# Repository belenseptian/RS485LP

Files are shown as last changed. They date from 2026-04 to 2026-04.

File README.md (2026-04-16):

-----

# RS-485LP (Low Power RS485 Node)

[](https://www.gnu.org/licenses/gpl-3.0)
[](https://platformio.org/)

**RS-485LP** is an open-source RS485 converter featuring a custom PCB and optimized PlatformIO firmware. It is designed to minimize power consumption for battery-operated sensors and remote monitoring systems.

🔗 **Official Project Website:** [https://belenseptian.github.io/RS485LP/](https://belenseptian.github.io/RS485LP/)

-----

### 📟 Board Design Preview
Below are the top and bottom views of the RS-485LP PCB.

| Top View (Components) | Bottom View (Traces) |
| :---: | :---: |
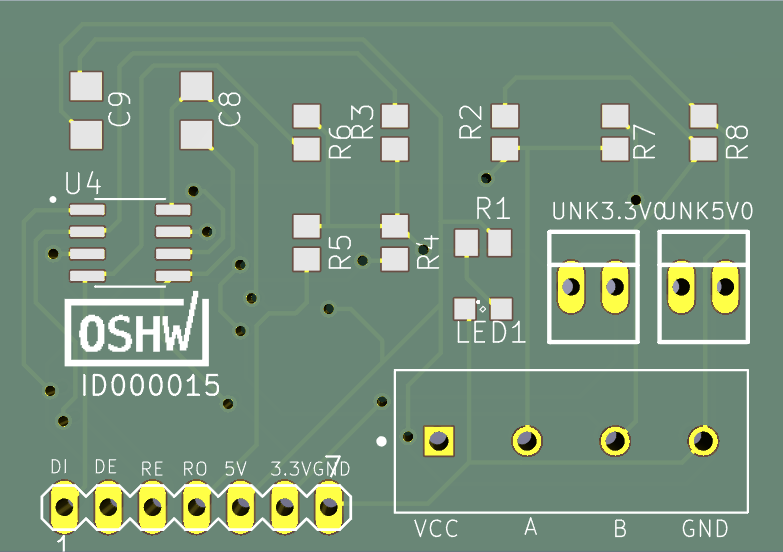
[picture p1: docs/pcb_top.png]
PCB Top
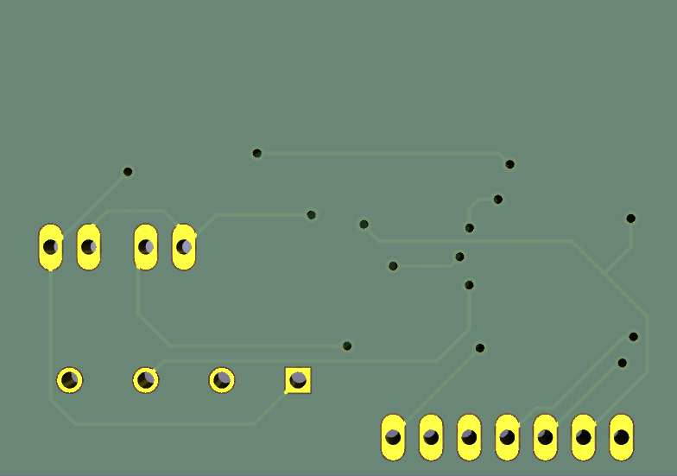
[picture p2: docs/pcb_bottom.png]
PCB Bottom
|  |  |

-----

## 🚀 Features

  * **Sleep & Shutdown Optimization:** Optimized for deep-sleep and hardware shutdown modes to achieve micro-amp current draw during periods of inactivity.
  * **RS485 Protocol:** Reliable differential signaling for long-range data transmission.
  * **PlatformIO Integrated:** Easy-to-compile and upload firmware using VS Code.
  * **Compact Form Factor:** Small PCB footprint suitable for tight enclosures.

-----

## 🛠 Hardware Fabrication

### 1\. Obtain KiCad Files

The PCB design is created using **KiCad**. You can find the project files in the `pcb/` directory.

1.  Clone this repository to get the full KiCad project.
2.  Open the project in KiCad to view the schematic or modify the layout.

### 2\. Ordering from PCBWay (or similar)

Most modern PCB manufacturers allow you to upload the KiCad file directly:

1.  **Option A (Direct):** Upload the `.kicad_pcb` file from the `pcb/` folder directly to [PCBWay's Instant Quote](https://www.pcbway.com/).
2.  **Option B (Manual Gerber Export):** - In KiCad, go to **File \> Fabrication Outputs \> Gerbers (.gbr)**.
      - Generate the drill files and zip all outputs together.
      - Upload the resulting `.zip` file to the manufacturer.

-----

## 💻 Software Setup

This project uses **PlatformIO** inside **Visual Studio Code**.

### Prerequisites

  * **VS Code:** [Download here](https://code.visualstudio.com/)
  * **PlatformIO IDE Extension:** Install this via the VS Code Extensions marketplace.

### Project Installation

1.  Clone the repository:
    ```bash
    git clone https://github.com/belenseptian/RS485LP.git
    ```
2.  Open VS Code and go to **PlatformIO Home** \> **Open Project**.
3.  Navigate to the `firmware/` folder and select it.

-----

## 📤 Uploading & Testing Sleep Mode

1.  **Connect Hardware:** Connect your board to your computer using a USB-to-Serial adapter.
2.  **Build & Upload:** Use the **Checkmark (✅)** to compile and the **Arrow (➡️)** to flash.
3.  **Verify Shutdown:**
      - Open the **Serial Monitor (🔌)** (Baud rate: `115200`).
      - The monitor should display "Entering Sleep Mode..." or "Shutting Down...".
      - Use a Multimeter or Power Profiler to measure the current draw; it should drop significantly as the MCU enters the deep sleep/shutdown state.
4.  **Wake-up Trigger:** Ensure you have configured the wake-up source (e.g., Timer or External Interrupt on the RS485 RX pin).

-----

## 🔌 Wiring Diagram

| Pin Name | Description | Connection |
| :--- | :--- | :--- |
| **VCC** | Power Input | Depend on the sensor specifications |
| **GND** | Ground | Ground |
| **A** | RS485 Data+ | Connect to Bus A |
| **B** | RS485 Data- | Connect to Bus B |

-----

## 📂 Project Structure

```text
RS-485LP/
├── firmware/           # PlatformIO project files
│   ├── src/            # Main application code (Sleep/Shutdown logic)
│   └── platformio.ini  # Project configuration
├── pcb/                # KiCad project files (.kicad_pcb, .kicad_sch)
├── docs/               # Datasheets and additional documentation
└── README.md           # This file
```

-----

## 📜 License

This project is licensed under the **GNU General Public License v3.0** - see the [LICENSE](https://www.google.com/search?q=LICENSE) file for details.

## 🤝 Contributing

Contributions are welcome\! If you have suggestions for better power-gating or further reducing shutdown current, feel free to open an **Issue** or submit a **Pull Request**.

-----

**Developed by [Belen Septian](https://www.google.com/search?q=https://github.com/belenseptian)**

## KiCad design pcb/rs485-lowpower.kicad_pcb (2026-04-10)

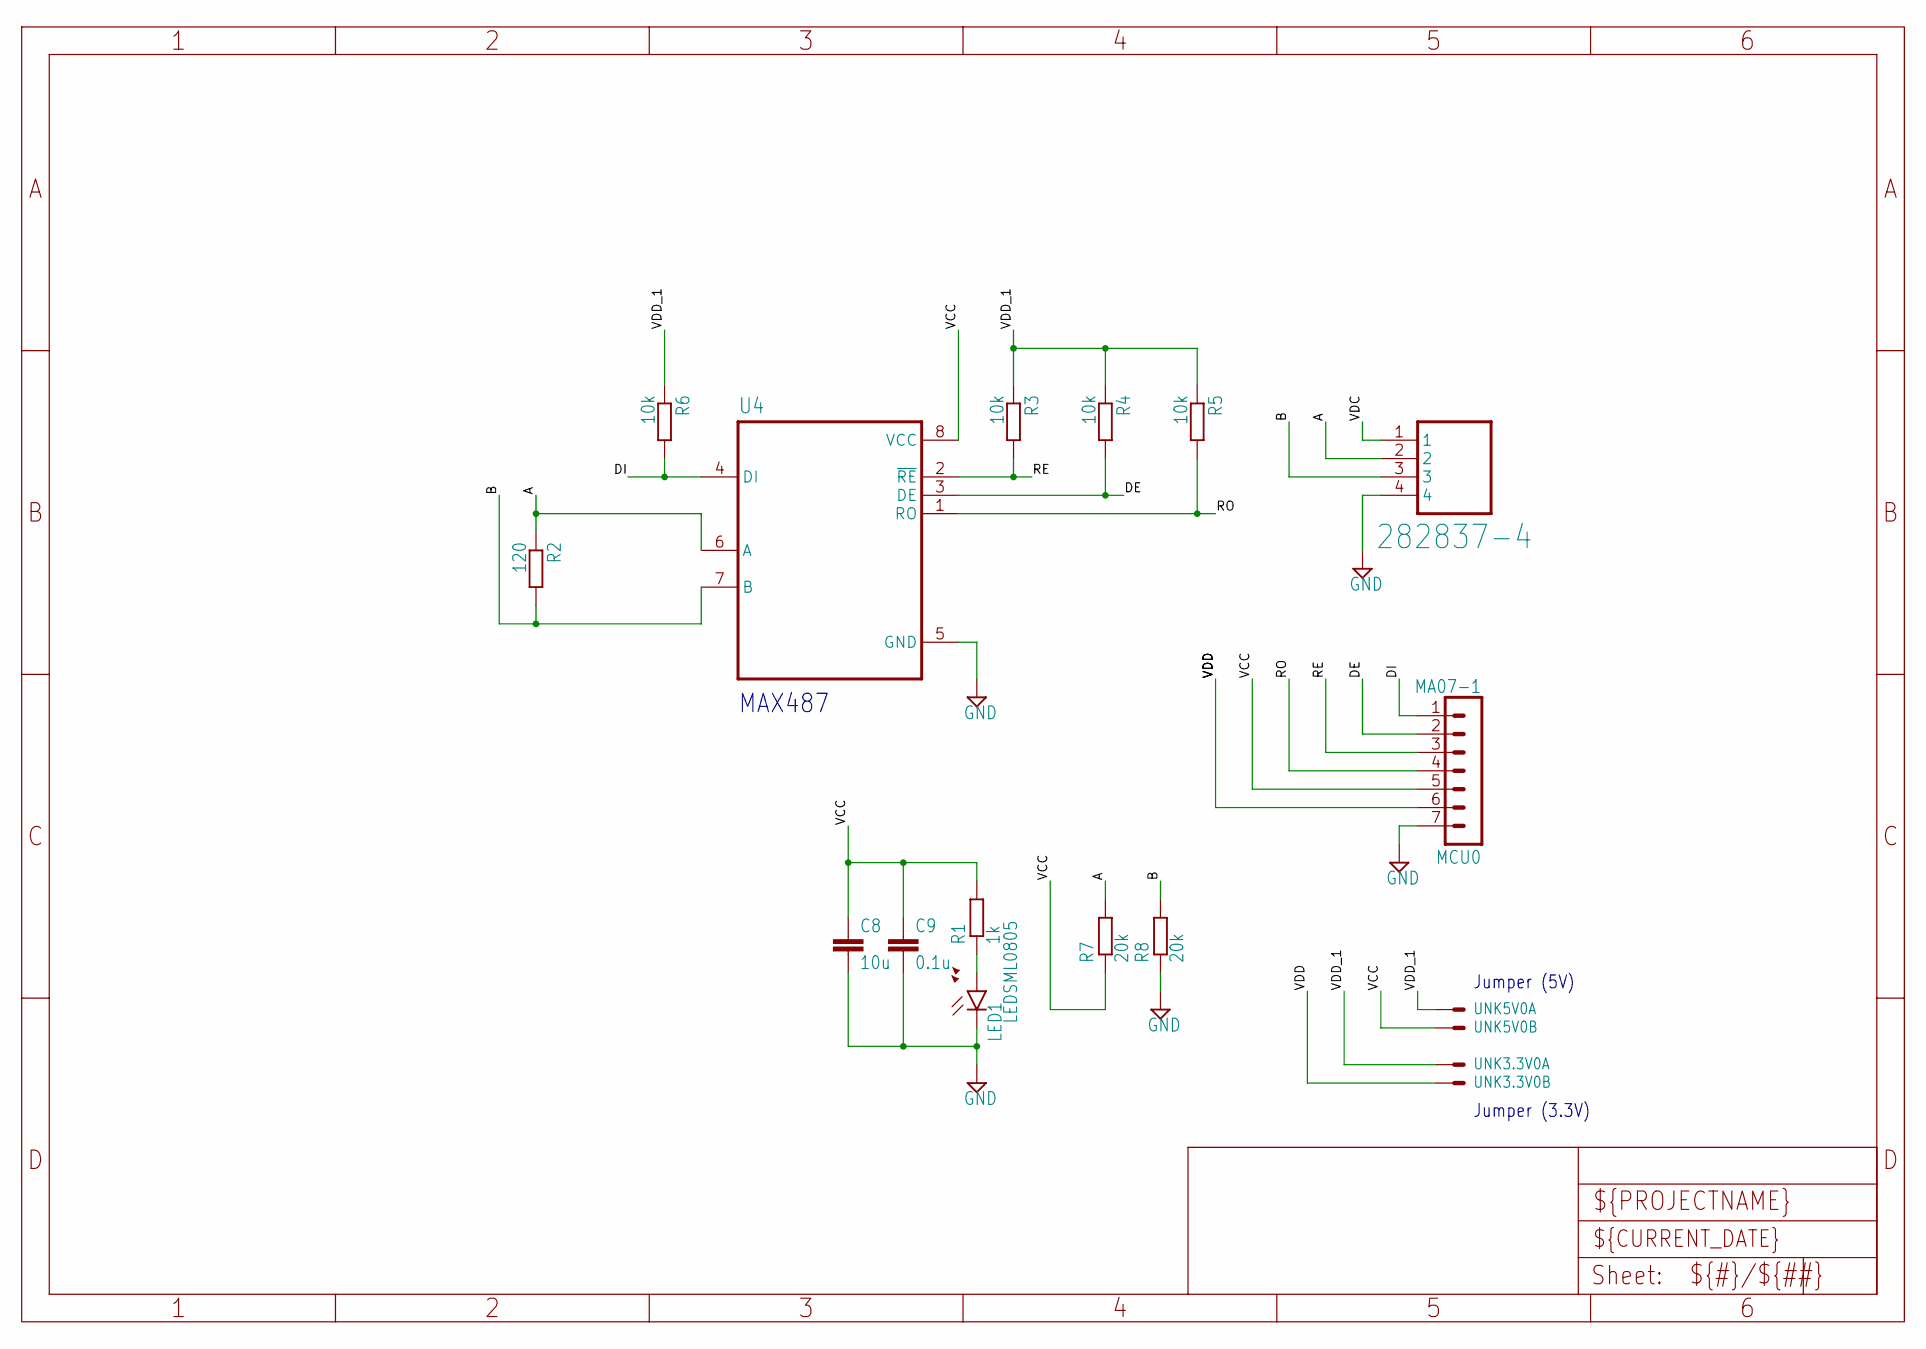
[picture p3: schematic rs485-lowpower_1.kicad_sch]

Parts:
C8: 10u; C1206
C9: 0.1u; C1206
LED1: LEDSML0805; SML0805
MCU0: MA07-1
R1: 1k; R0805
R2: 120; R0805
R3, R4, R5, R6: 10k; R0805
R7, R8: 20k; R0805
RS485-UGMLPV1.0: 282837-4; TE_282837-4
U4: MAX485CSA+T; SOIC127P600X175-8N
UNK3.3V0, UNK5V0: VAC; 22-23-2021

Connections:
A: R2.1, R7.2, RS485-UGMLPV1.0.2, U4.6 (A)
B: R2.2, R8.2, RS485-UGMLPV1.0.3, U4.7 (B)
DE: MCU0.2, R4.2, U4.3 (DE)
DI: MCU0.1, R6.2, U4.4 (DI)
GND: C8.2, C9.2, LED1.C, MCU0.7, R8.1, RS485-UGMLPV1.0.4, U4.5 (GND)
unnamed: LED1.A, R1.1
RE: MCU0.3, R3.2, U4.2 (~RE)
RO: MCU0.4, R5.2, U4.1 (RO)
VCC: C8.1, C9.1, MCU0.5, R1.2, R7.1, U4.8 (VCC), UNK5V0.2
VDC: RS485-UGMLPV1.0.1
VDD: MCU0.6, UNK3.3V0.2
VDD_1: R3.1, R4.1, R5.1, R6.1, UNK3.3V0.1, UNK5V0.1

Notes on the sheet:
Jumper (3.3V)
MAX487
Jumper (5V)

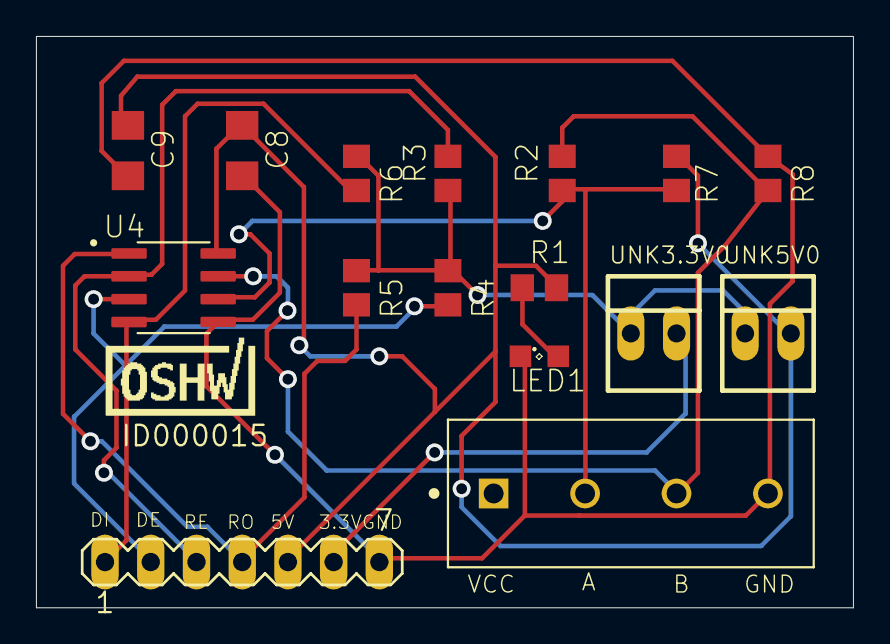
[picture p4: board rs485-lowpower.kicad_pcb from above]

Board: 2 copper layers, 45.4 x 31.7 mm, 17 parts (0 on the bottom side), 11 nets.

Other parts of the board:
U$1: ID000015; CERT-SMALL-SILK

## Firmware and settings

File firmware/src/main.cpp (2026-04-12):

#include <Arduino.h>
// ---------- This is a testing code for MD02 temperature and humidity sensors, you may change the registers as per your need ------------
// In this example we use Serial2 ESP32, you may change to other serials or softwareserial
// UART pins
#define RS485_TX 17
#define RS485_RX 16
// MAX487 pins
#define DE 19
#define RE 18
// No.Parameters
#define PARAMS    2
#define REQ_FRAME 8
#define RES_FRAME 16
#define MODBUS_BAUD_RATE 9600

// Response bytes
uint8_t expectedBytes = 9; // 1(ID) + 1(Func) + 1(ByteCount) + 4(Data) + 2(CRC) = 9 bytes

// ---------- MAX487 MODES ----------
// Transmit mode
void enableTransmit()
{
  digitalWrite(RE, HIGH);
  digitalWrite(DE, HIGH);
}

// Receive mode
void enableReceive()
{
  digitalWrite(RE, LOW);
  digitalWrite(DE, LOW);
}

// Shutdown mode (LOW POWER)
void enableShutdown()
{
  digitalWrite(RE, HIGH);
  digitalWrite(DE, LOW);
}

// ---------- MODBUS CRC CALCULATION ----------
uint16_t calculateCRC(uint8_t *buffer, uint8_t length) 
{
  uint16_t crc = 0xFFFF;
  for (int pos = 0; pos < length; pos++) {
    crc ^= (uint16_t)buffer[pos];
    for (int i = 8; i != 0; i--) {
      if ((crc & 0x0001) != 0) {
        crc >>= 1;
        crc ^= 0xA001;
      } else {
        crc >>= 1;
      }
    }
  }
  return crc;
}

void setup()
{
  pinMode(RE, OUTPUT);
  pinMode(DE, OUTPUT);

  // Start in shutdown mode
  enableShutdown();

  Serial.begin(115200);
  Serial2.begin(MODBUS_BAUD_RATE, SERIAL_8N1, RS485_RX, RS485_TX);
}

void loop()
{
  uint16_t data[PARAMS];

  // Wake MAX487 before communication
  enableReceive();
  delay(5); // Stabilization time

  // ---------- CONSTRUCT MODBUS REQUEST ----------
  // Slave ID: 1, Function Code: 4 (Read Input Registers), Start Addr: 0x0001, Quantity: 2
  uint8_t requestFrame[REQ_FRAME] = {0x01, 0x04, 0x00, 0x01, 0x00, 0x02, 0x00, 0x00};
  
  // Calculate CRC for the first 6 bytes
  uint16_t crc = calculateCRC(requestFrame, 6);
  requestFrame[6] = crc & 0xFF;         // CRC Low Byte
  requestFrame[7] = (crc >> 8) & 0xFF;  // CRC High Byte

  // ---------- SEND REQUEST ----------
  enableTransmit();
  Serial2.write(requestFrame, 8);
  Serial2.flush(); // CRITICAL: Wait until all bytes are actually transmitted over UART
  enableReceive();

  // ---------- READ RESPONSE ----------
  uint8_t responseFrame[RES_FRAME];
  uint8_t bytesRead = 0;
  unsigned long startTime = millis();
  
  // Read with a timeout of 1000ms
  while ((millis() - startTime < 1000) && (bytesRead < expectedBytes)) {
    if (Serial2.available()) {
      responseFrame[bytesRead++] = Serial2.read();
    }
  }

  // ---------- PARSE AND VALIDATE ----------
  if (bytesRead == expectedBytes) 
  {
    // Verify CRC of the received frame (excluding the 2 CRC bytes at the end)
    uint16_t receivedCRC = responseFrame[7] | (responseFrame[8] << 8);
    uint16_t calculatedCRC = calculateCRC(responseFrame, 7);

    if (receivedCRC == calculatedCRC) 
    {
      // Verify Slave ID, Function Code, and Byte Count match expectations
      if (responseFrame[0] == 0x01 && responseFrame[1] == 0x04 && responseFrame[2] == 0x04) 
      {
        // Extract data (Modbus transmits High Byte first)
        data[0] = (responseFrame[3] << 8) | responseFrame[4];
        data[1] = (responseFrame[5] << 8) | responseFrame[6];
        
        Serial.println(data[0]);
        Serial.println(data[1]);
      } 
      else 
      {
        Serial.println("Modbus Error: Unexpected response format/error frame.");
      }
    } 
    else 
    {
      Serial.println("Modbus Error: CRC failed.");
    }
  } 
  else 
  {
    Serial.print("Modbus Error: Timeout or incomplete data. Bytes read: ");
    Serial.println(bytesRead);
  }

  // Enter shutdown mode after communication
  enableShutdown();
  delay(1000);
}

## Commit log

2026-04-10 add pcb and schematic designs
    [rs485-lowpower.kicad_pcb, rs485-lowpower_1.kicad_sch]
2026-04-10 Update README to clarify PCB description
2026-04-10 reupload pcb file
    [rs485-lowpower.kicad_pcb, rs485-lowpower_1.kicad_sch]
2026-04-11 add gerber files
